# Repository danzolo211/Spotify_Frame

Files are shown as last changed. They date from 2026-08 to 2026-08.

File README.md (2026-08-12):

# GraceFrame ✝

An e-ink frame for the person you love. When she plays Spotify it shows her
music — album art, title, progress, and live synced lyrics where available.
When the music stops, it quietly turns into Scripture: **135 NIV verses** over **18 hand-drawn,
postcard-style scenes** (three crosses at dawn, a shepherd's field, a moonlit
starry night…), a new one every 20 minutes. Each verse is paired only with a
scene that has room for it, so the words are always complete and razor-sharp.

And it's hers to hold: a **phone app** (no App Store needed) shows a live
mirror of the screen, lets her browse and search every verse, save favorites
(they appear more often), pick scenes, and receive **notes** you send in
handwriting — from her Wi-Fi *or from anywhere* (see “Send her a note from
anywhere,” below).

Extra graces built in:
- **Quiet hours** — the frame holds one verse of peace all night, no flashing.
- **Special dates** — birthdays/anniversaries greet her by name in the morning.
- **Skip-proof e-ink** — rapid song-skipping never wears the panel (see below).

---

## 1. What's in this folder

```
Spotify_Frame/       <- the Arduino sketch (open Spotify_Frame.ino)
  data/              <- goes onto the ESP32's flash: verses, scenes, web app
  font_*.h           <- generated fonts (script, serif, sans)
  config.h           <- personalization: her name, dates, timezone, pins
  secrets.h          <- Wi-Fi + Spotify credentials (keep private!)
tools/               <- asset pipeline (already run — outputs are committed)
  make_backgrounds.py  fetch_verses.py  make_fonts.py
  spotify_auth.py      preview_app.py
WIRING.md            <- how to wire (do this first)
README.md            <- you are here
```

Everything in `Spotify_Frame/data` and the fonts are **already generated** —
you don't need to run any Python unless you want to tweak scenes or verses.

**Try the app right now** (before the hardware arrives):
`python tools/preview_app.py` → open http://localhost:8080 on this PC.

## 2. Wire it

Follow **WIRING.md** (5 minutes, 8 wires).

## 3. Arduino IDE setup (once)

1. Install **Arduino IDE 2.x**.
2. *File → Preferences → Additional boards manager URLs*, add:
   `https://espressif.github.io/arduino-esp32/package_esp32_index.json`
3. *Boards Manager* → install **esp32 by Espressif Systems**.
4. *Library Manager* → install:
   **GxEPD2** · **Adafruit GFX Library** · **ArduinoJson** · **TJpg_Decoder**
5. Optional if you use the IDE: install the LittleFS uploader (for step 6):
   download
   `arduino-littlefs-upload-*.vsix` from
   https://github.com/earlephilhower/arduino-littlefs-upload/releases
   and drop it into `C:\Users\<you>\.arduinoIDE\plugins\`
   (create the folder if needed), then restart the IDE.

## 4. Personalize

- `Spotify_Frame/config.h` — set `HER_NAME`, add `SPECIAL_DATES`
  (birthday, anniversary…), check `TIMEZONE`.
- `Spotify_Frame/secrets.h` — set **her home Wi-Fi** in `WIFI_SSID`/`WIFI_PASS`
  so she never has to configure anything, and confirm the Spotify values (see §9
  — the refresh token must belong to the account whose music you want shown).

## 5. Flash the firmware and data

Recommended from PowerShell on this PC:

```
cd C:\Users\Daniel Weber\OneDrive\Desktop
.\build_spotify_frame.ps1 -Upload -UploadData -Port COM6
```

That script pins a stable Arduino CLI, refuses to upload if compile fails, flashes
the firmware, then rebuilds and uploads the LittleFS data image with the scenes,
verses, and phone app.

If you use Arduino IDE instead, open `Spotify_Frame/Spotify_Frame.ino`. Select
**Tools →**
- Board: **ESP32S3 Dev Module**
- USB CDC On Boot: **Default / Disabled**
- PSRAM: **OPI PSRAM**
- Flash Size: **16MB**
- Partition Scheme: **16M Flash (3MB APP/9.9MB FATFS)**
- Port: your COM port

Click **Upload**. (If upload won't start: hold the BOOT button, tap RESET,
release BOOT, retry.)

## 6. Upload the data (verses, scenes, app)

The PowerShell command above already does this when you include `-UploadData`.

In Arduino IDE, with the sketch still open: press **Ctrl+Shift+P**, run
**“Upload LittleFS to Pico/ESP8266/ESP32”**. This copies `Spotify_Frame/data`
onto the board (~1 MB, takes a minute). Close the Serial Monitor first —
the uploader needs the port.

## 7. First light

- The frame connects to Wi-Fi and shows its first verse. Play Spotify
  anywhere on her account → the frame follows within ~5 seconds. If synced
  lyrics are available, one clean line appears under the album art.
- If Wi-Fi fails it opens its own network **GraceFrame-Setup** — join it
  with a phone and pick the home network. After credentials work, the panel
  confirms the SSID, IP address, and `graceframe.local`.

## 8. Put the app on her phone

1. On her phone (same Wi-Fi), open **http://graceframe.local**
   (if her phone balks at `.local`, use the frame's IP — it's printed in
   the Serial Monitor at boot).
2. Share → **Add to Home Screen**. Done — it opens full-screen like a real
   app, icon and all.

## 8½. Send her a note from anywhere

When you're **on her Wi-Fi**, the app's **Notes** tab sends straight to the
frame. When you're **not** — at your place, at work — use **`send-note.html`**:

1. Open `send-note.html` on **your** phone (email/AirDrop it to yourself, or
   host it anywhere — even a free GitHub Pages). Share → **Add to Home Screen**
   so it's one tap away.
2. Type a message, tap **Send to frame**. It appears on her frame within a few
   seconds, in handwriting — no matter whose network you're on.

How it works: the frame quietly checks a **private channel** on the free
[ntfy.sh](https://ntfy.sh) service; `send-note.html` posts to that same channel.
The channel name is a shared secret defined as `NOTES_TOPIC` in the ignored
`Spotify_Frame/secrets.h`. The QR generator reads it from there and puts it in
your private `send-note.html?token=...` link. To rotate it, set a new random
topic in `secrets.h`, rerun `python tools/make_qr.py`, and replace the private
QR/link. Notes pass through ntfy.sh's public relay, so keep them sweet, not
secret. Leave `NOTES_TOPIC` blank to turn the remote path off; the on-Wi-Fi
Notes tab still works.

Want to check the pipe is live? `python tools/test_remote_note.py` publishes a
test note and confirms it comes back.

## 9. Spotify

The refresh token in `secrets.h` already follows the account it was made
with. To follow **her** account instead, make sure her account (or your
family account) is the one that authorized it. To re-link:

```
python tools/spotify_auth.py --id CLIENT_ID --secret CLIENT_SECRET --device graceframe.local
```

(Client ID/secret from https://developer.spotify.com — the app needs
redirect URI `http://127.0.0.1:8888/callback`.)

---

## How the panel is protected (why skipping songs won't hurt it)

- A new song must **survive 2.5 s** before it's drawn — a skip-storm
  settles to a single refresh of the song she lands on.
- Full-screen refreshes are hard-limited to one per 3 s. Lyric/timer strip
  refreshes share a separate 900 ms gate so they can stay in sync without
  hammering the panel.
- Each **new song is a clean full refresh**, so the previous title/art is
  wiped instead of ghosting under the next one. Within the same song, lyric
  changes clean just the lyric strip. Timer ticks use one masked clean transaction
  over the bottom progress window: only the elapsed-time digits and the moving
  fill edge are cleaned through white, with the previous progress strip preserved
  during phase 1 so the fill cannot jump ahead during the clean pass. Small
  Spotify polling jitter is ignored; real seeks still snap.
- The elapsed time is **interpolated locally** between Spotify polls, so it
  stays accurate without extra network calls; the bar repaints every 10 s by
  default.
- Verse changes are calm full refreshes every 20 min (~70/day — panels are
  rated for 1,000,000+).
- During **quiet hours** the panel doesn't refresh at all; e-ink holds the
  image with zero power.

## Tweaks & tools

| I want to… | Do this |
|---|---|
| Change rotation timing, quiet hours, her name | In the app → Settings |
| Add/redraw scenes | edit `tools/make_backgrounds.py`, run it, re-do step 6 |
| Change verse list / translation | edit `tools/fetch_verses.py`, run it (`--translation KJV` etc.), re-do step 6 |
| Different fonts/sizes | edit `tools/make_fonts.py`, run it, re-flash (step 5) |
| Panel blank/scrambled | switch panel line in `config.h` (see WIRING.md #5) |

**Note on the text:** verses come from bolls.life's NIV text (the classic
1984 edition) for personal, non-commercial use — perfect for a gift, not
for resale.

Built with love (and a soldering-free ribbon cable). 🤍

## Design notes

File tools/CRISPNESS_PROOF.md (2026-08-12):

# Why the GraceFrame backgrounds cannot be blurry or grainy

A short proof that the art is crisp by construction — not by luck — at three
levels: the data, the transform that makes it, and the panel that shows it.
Any softness you ever see is your *screen viewer* rescaling hard pixels; it is
not in the bytes we ship, and it cannot appear on the e‑ink glass.

## 1. The data has exactly two states, so blur is unrepresentable
Each background is a packed 1‑bit bitmap: `BG_BYTES = 15000 = 400 × 300 / 8`
(`bgs.h`). Every pixel's value `L(x, y) ∈ {0, 1}` — black or white, nothing
between.

Blur *is*, by definition, a continuous luminance gradient across space: a ramp
that passes through **three or more** distinct levels within a small
neighborhood. A function whose codomain has cardinality 2 cannot take an
intermediate value, so it cannot form such a ramp. Between any two adjacent
pixels the transition is a single Heaviside step of width ≤ 1 pixel. **There is
no third level to interpolate ⇒ no blur can exist in the stored image.**

## 2. Generation is a threshold (a step function), never a filter
The generator (`make_backgrounds.py`) draws each scene at 4× (1600 × 1200) in
8‑bit grayscale, area‑resamples to 400 × 300, then maps every pixel with

```
T(L) = 1 if L < 128 else 0        # PIL convert("1", dither=NONE)
```

`T` is a pure step function, and `dither=NONE` means **no quantization error is
diffused into neighboring pixels** — the mechanism that would create scattered
mid‑tone dots ("grain") is simply never invoked. Composing any grayscale render
with `T` yields a codomain of `{0, 1}`. The 4× supersample‑then‑threshold also
pins the maximum edge‑transition width to exactly **one device pixel**
(Nyquist‑limited): edges are as sharp as the addressable grid allows — provably
the sharpest an image on this panel can be.

## 3. The panel is bistable, so blur is physically impossible on the glass
The Waveshare 4.2″ (SSD1683) drives each pixel to *full* black or *full* white;
it has **no grayscale addressing**. The display map `D : {0,1} → {black, white}`
is a 2‑level step, so the physical luminance is piecewise‑constant on the pixel
grid. A blur needs ≥ 3 luminance levels; with 2 it cannot form. (This is also
why the design forbids dithering: a dithered photo only *simulates* grey by
scattering black dots — the exact "grain" we refuse.)

## 4. Grain is driven to zero by construction — and measured, not assumed
Define a **speckle** as a foreground pixel whose 8 neighbours are all background
— an isolated floating dot, the visual signature of grain. The design language
(a) forbids dithering, and (b) enforces a minimum stroke width (≈1.4 px) and
minimum parallel‑line spacing (≈3 px). After threshold, no connected component
smaller than the feature size can survive, so free‑floating speckles → 0.

This is verified, not just argued: `audit_backgrounds.py` counts 8‑neighbour
speckles for every scene and **fails the build** if any scene's declared verse
zone contains a single foreground pixel. Current result: **0 zone violations**
across all 18 scenes (so words can never overlap art), and ≈0 floating speckles
on the day scenes — the handful that remain are *intentional* marks (sea spray
on the Great Wave; wheat awns; the ruled lines on the open book), not threshold
grain.

## Conclusion
Blur and grain aren't merely unlikely here — they are **excluded** by the
representation (2 states), the transform (threshold, zero error diffusion), and
the device (bistable). QED.

## Appendix: why live lyric and timer strips do not leave old pixels

The live lyric band and elapsed-time box use the same two-phase update:

```
1. set every pixel in rectangle R to white
2. refresh only R
3. draw the new content into R
4. refresh only R again
5. copy only R into the panel's previous-RAM baseline
```

Let `G_t(x,y)` be the visible glass state after update `t`, and `C_t(x,y)` be
the canvas state for the next content. For every pixel inside the strip
rectangle `R`, phase 1 forces `G_t(x,y)=white`. Phase 2 then drives the pixel
from white to exactly `C_t(x,y)`. Therefore the final state is
`G_t(x,y)=C_t(x,y)` for all `(x,y) in R`, independent of what was displayed at
`t-1`. Old glyphs cannot remain because the old state is not part of the second
transition.

For every pixel outside `R`, the clean helper writes neither current RAM nor
previous RAM, and the e-paper controller is asked to refresh only `R`. Therefore
`G_t(x,y)=G_{t-1}(x,y)` outside `R`. That is the key invariant:

```
previous_R_t == G_t on R
previous_outside_R_t == previous_outside_R_(t-1)
```

The lyric and progress rectangles are disjoint in the firmware constants:

```
Lyric band R_lyric: x = 0..399, y = 199..234
Transport icons:    y = 235..263
Progress bar box:   x = 16..383, y = 266..279
Elapsed time box:   x = 16..95,  y = 282..299
```

The full bottom strip contains the full timer/bar draw area:

```
Bar border: x = 18..381, y = 267..278
Bar fill:   x = 20..379, y = 269..276
Time text:  baseline y = 295; SansSmall digits occupy y = 286..294
```

`R_lyric` is disjoint from every progress rectangle, separated by the transport
icon rows. A lyric update uses `R = R_lyric`; it cannot blank, repaint, or
visibly flash the progress bar, timestamps, play/pause button, or skip arrows
because the clean helper writes only `R_lyric` into current RAM, previous RAM,
and the partial-refresh window.

Normal timer ticks also minimize flashing. The progress tick uses one masked
two-phase update over the bottom progress window. Its clean set is the small
elapsed-time box plus only the moving edge of the progress fill. Phase 1 copies
the previous displayed progress strip, not the future canvas, then whites only
the clean set. Phase 2 writes the final canvas. Therefore the fill cannot jump
ahead during the clean phase, and unchanged bar/frame pixels do not get a white
blink. If Spotify seeks backward and the bar must shrink, the firmware cleans
the fill interior so old black pixels are erased.

The coordinate invariant is explicit in `config.h`: lyrics are rows 199..234
and the progress/timestamp strip is rows 266..299. Because the lyric partial
push is confined to `LYRIC_BAND_*`, it cannot address the timestamp or progress
pixels at all. Progress ticks are also held away from lyric-line changes by
`PROGRESS_LYRIC_GUARD_MS`, so a legitimate timestamp clean pass is not scheduled
on top of the lyric transition and mistaken for lyric-induced erasing.

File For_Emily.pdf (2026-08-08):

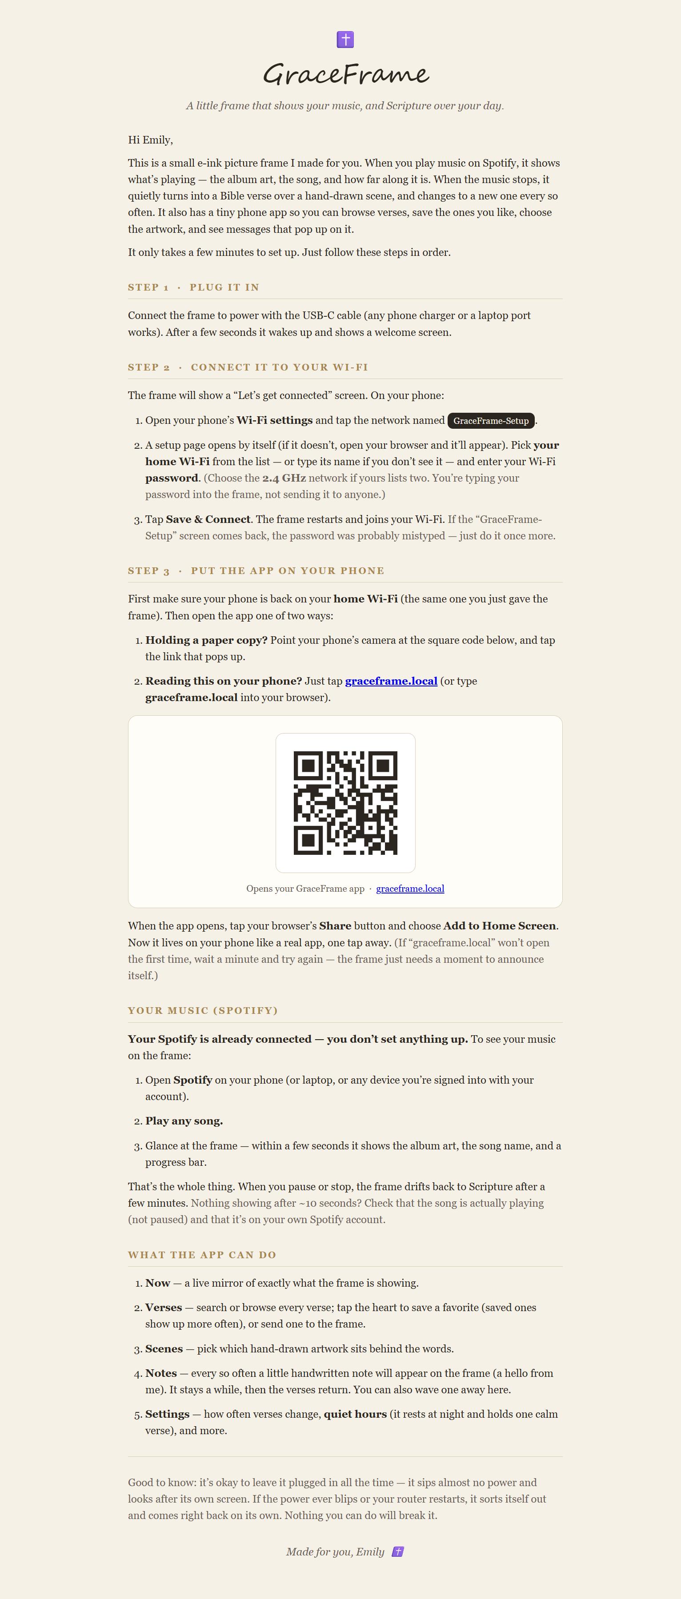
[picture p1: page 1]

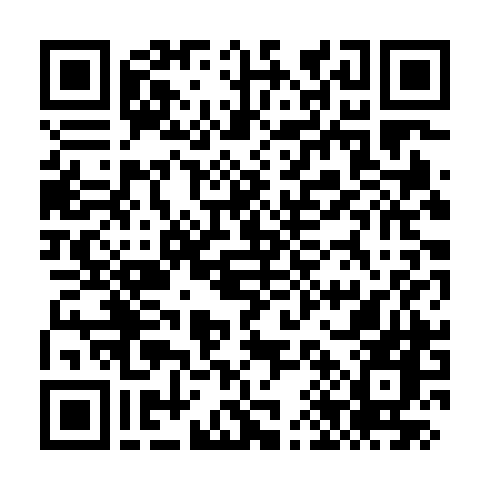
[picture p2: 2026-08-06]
graceframe_remote_qr.png

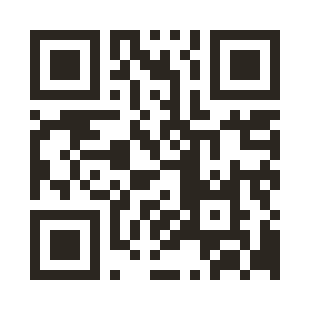
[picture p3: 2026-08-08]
graceframe_local_qr.png

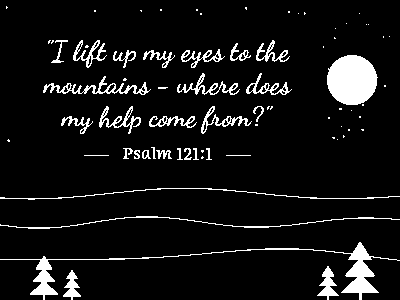
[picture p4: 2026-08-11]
tools/previews/review/13_moonlit-hills.png

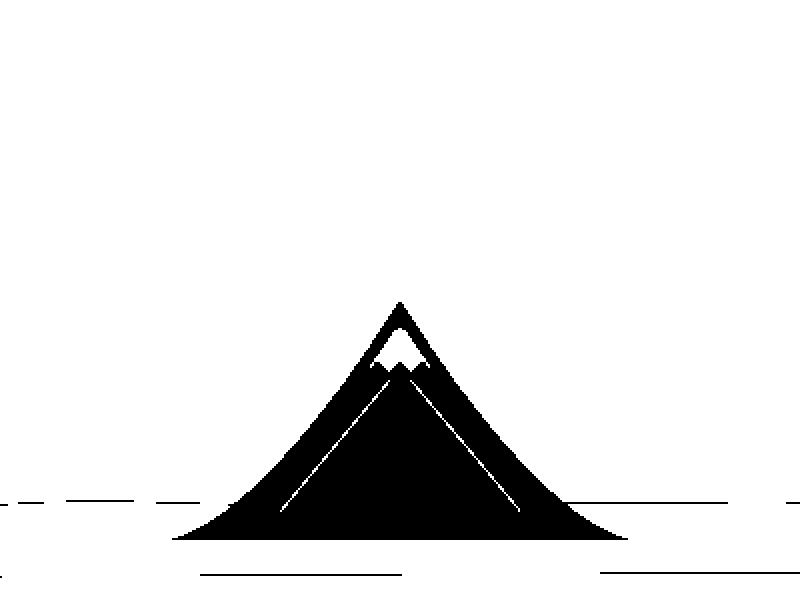
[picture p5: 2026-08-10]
tools/previews/015_fuji-serene.png

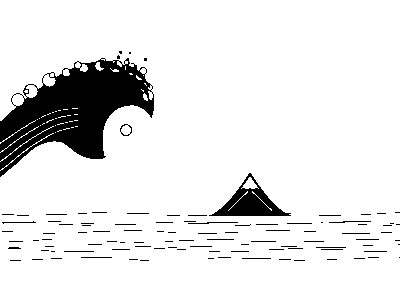
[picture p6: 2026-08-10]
tools/previews/review/15_great-wave_art.png

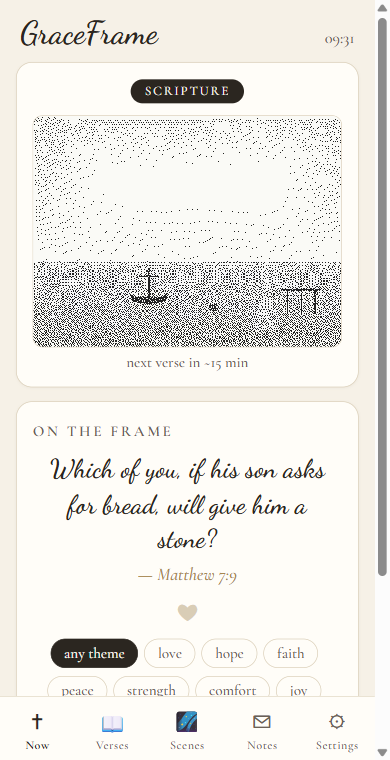
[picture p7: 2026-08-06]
tools/previews/app_now.png

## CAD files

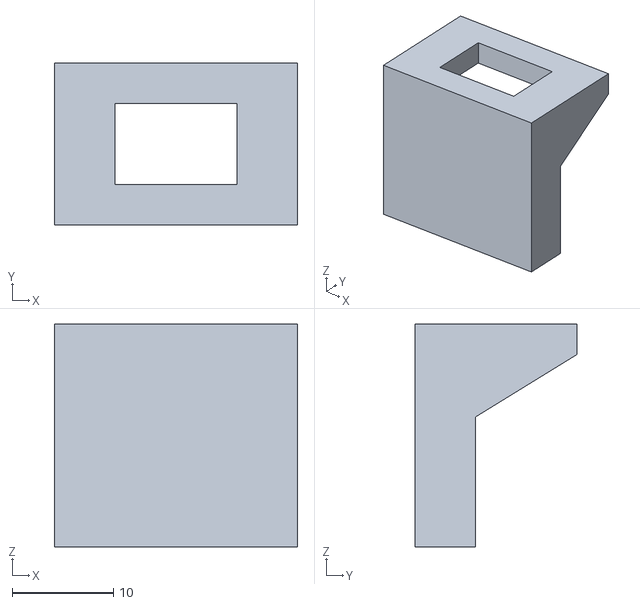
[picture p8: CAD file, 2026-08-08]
USBC_Base_Bracket.stl
24.0 x 16.0 x 22.0

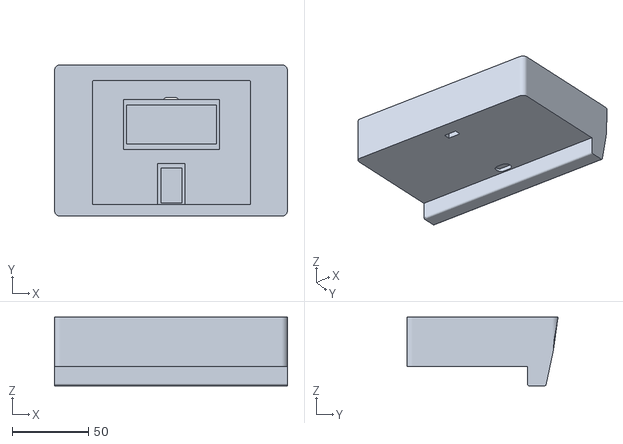
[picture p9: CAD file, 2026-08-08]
V_3_Daniel_Weber_Stand.stl
152.4 x 99.1 x 45.1

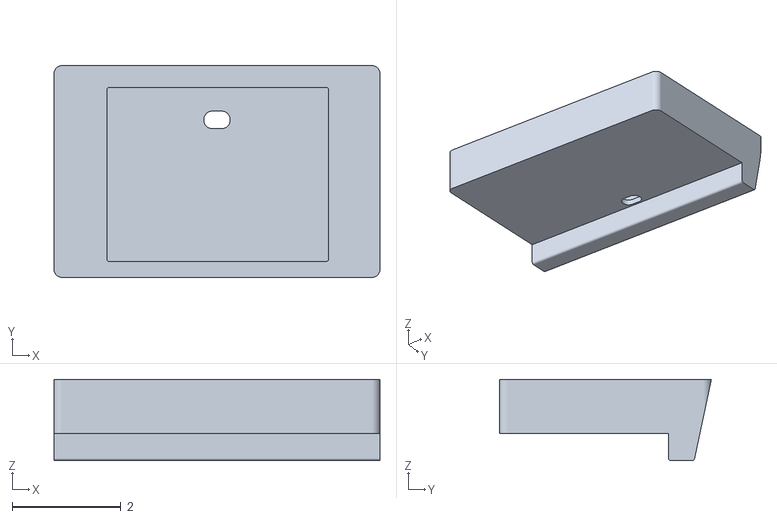
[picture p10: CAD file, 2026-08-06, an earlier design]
V_2_Daniel_Weber_Stand.stl
6.00 x 3.90 x 1.50

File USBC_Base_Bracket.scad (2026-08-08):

// USB-C base bracket for V_2_Daniel_Weber_Stand
// Holds a panel-mount USB-C female jack in the open bottom-center of the stand.
// Edit the numbers, then render (F6) and export STL.  Identical defaults to
// tools/make_base_bracket.py -- use whichever you prefer.
//
// Orientation when installed: +Z points to the REAR (the jack faces out the open
// back of the base); the FRONT face (Z=0) butts the solid front bezel so plugging
// a cable in can't push the bracket inward. Print with the FLOOR on the bed.

/* ---- tune to YOUR jack (mm) ---- */
pocket_depth = 22.0;  // front-to-back; keep == stand pocket depth so it wedges
width        = 24.0;
height       = 16.0;
floor_t      = 3.0;
panel_t      = 3.0;

aper_w   = 12.0;      // jack aperture width  (jack body + ~0.5 mm)
aper_h   = 8.0;       // jack aperture height
aper_yc  = 8.0;       // aperture center above the floor

screw_holes   = false; // set true if your jack mounts with 2 screws
screw_spacing = 16.0;  // center-to-center
screw_dia     = 2.2;   // M2 clearance

rail_t = 2.5; rail_h = 6.0;      // side rails
gusset_l = 8.0; gusset_h = 13.0; // panel-to-floor braces
$fn = 32;

module gusset(cx)
  // right-triangle brace on the panel front face, spanning rail width at x=cx
  translate([cx - rail_t/2, floor_t, pocket_depth - panel_t])
    rotate([0,90,0])
      linear_extrude(rail_t)
        polygon([[0,0],[0,-gusset_l],[gusset_h,0]]);

difference() {
  union() {
    // floor (rests on the stand's internal shelf)
    translate([-width/2, 0, 0]) cube([width, floor_t, pocket_depth]);
    // rear panel (solid; aperture cut below)
    translate([-width/2, 0, pocket_depth - panel_t]) cube([width, height, panel_t]);
    // side rails
    translate([-width/2, 0, 0]) cube([rail_t, rail_h, pocket_depth]);
    translate([ width/2 - rail_t, 0, 0]) cube([rail_t, rail_h, pocket_depth]);
    // gussets at the outer edges (clear of the central jack body)
    gusset(-width/2 + rail_t/2);
    gusset( width/2 - rail_t/2);
  }
  // jack aperture through the rear panel
  translate([-aper_w/2, aper_yc - aper_h/2, pocket_depth - panel_t - 0.5])
    cube([aper_w, aper_h, panel_t + 1.0]);
  // optional screw holes
  if (screw_holes)
    for (sx = [-screw_spacing/2, screw_spacing/2])
      translate([sx, aper_yc, pocket_depth - panel_t - 0.5])
        cylinder(d = screw_dia, h = panel_t + 1.0);
}

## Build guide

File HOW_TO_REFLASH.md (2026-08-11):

# How to re-flash GraceFrame

Follow this any time you update the frame. **Every final update should include
firmware and data**: code plus `Spotify_Frame/data` (verses, scenes, phone app).
It takes about 5 minutes.

> **This latest update needs BOTH A and B** (the code and the app both changed).

---

## Recommended PowerShell path

1. Plug the frame into this computer with the USB-C cable.
2. Close Serial Monitor or any terminal using the COM port.
3. Run:

```
cd C:\Users\Daniel Weber\OneDrive\Desktop
.\build_spotify_frame.ps1 -Upload -UploadData -Port COM6
```

The script refuses to upload stale firmware if compile fails. `-UploadData`
rebuilds and writes the LittleFS image at `0x610000`; Wi-Fi, Spotify credentials,
and settings in NVS are not touched.

## Arduino IDE fallback

Open **Arduino IDE** and open `Spotify_Frame/Spotify_Frame.ino`. In the **Tools**
menu, set these exactly:
   - **Board:** ESP32S3 Dev Module
   - **USB CDC On Boot:** Default / Disabled
   - **PSRAM:** OPI PSRAM
   - **Flash Size:** 16MB
   - **Partition Scheme:** 16M Flash (3MB APP/9.9MB FATFS)
   - **Port:** the COM port that appears when you plug the frame in (e.g. `COM5`).
     Not sure which? Unplug the frame, look at the list, plug it back in — the
     new one that appears is it.

---

## Part A — Flash the firmware (the code)

1. **Close the Serial Monitor** if it's open (it holds the port and blocks uploads).
2. Click the **Upload** button — the round **→** arrow at the top-left.
3. Wait until the bottom says **"Done uploading."** (about 1–2 minutes).

**If the upload won't start / errors out:** hold the **BOOT** button on the board,
tap **RESET** once, let go of **BOOT**, then click **Upload** again.

---

## Part B — Upload the data (verses, scenes, phone app)

1. Keep the same sketch open, **Serial Monitor still closed**.
2. Press **Ctrl + Shift + P** (opens the command palette).
3. Start typing and choose: **"Upload LittleFS to Pico/ESP8266/ESP32"**.
4. Wait about a minute for it to finish.

> Don't see that command? Install the uploader plugin once (README §3, step 5),
> restart Arduino IDE, and try again.

Uploading data replaces the LittleFS data partition, including generated
backgrounds/web app/verses and `favs.bin` if present. NVS values such as Wi-Fi
and Spotify credentials are separate and survive it.

---

## When you only changed one thing

| What changed | What to upload |
|---|---|
| Firmware / `.cpp` / `.h` / `.ino` / `config.h` | **A only** |
| Phone app (`data/www/…`), verses, or scenes (`data/…`) | **B only** |
| Not sure, or a big update like this one | **Do BOTH** |

---

## Done

Unplug it from the computer and plug it into any USB charger. It boots, joins
Wi-Fi, and shows a verse within a few seconds. Play Spotify and it appears.

**First time at her place:** it won't know her Wi-Fi yet, so it shows the
"Let's get connected" screen — that's expected. She sets it herself with the
letter in `For_Emily.html` (she never has to give you her password).

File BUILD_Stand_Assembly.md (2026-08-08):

# GraceFrame — Integrated Stand (V_3) Assembly

`V_3_Daniel_Weber_Stand.stl` is the original stand **edited** into an Aura-style,
self-contained frame: deepened 7 mm and given a built-in electronics bay.

Regenerate any time with `python tools/edit_stand.py` (all sizes are parameters at
the top). Preview: `tools/_v3_preview.png` (cutaway + back + side fit schematic).

> **`V_3` is in real millimeters** — import normally (no ×25.4 like the inch original).

## What changed vs V_2
- **+7 mm depth** → cavity ~24 mm (comfortable room for display + ESP + adapter).
- **USB-C port** cut through the back wall, bottom-center (cable exits behind = Aura).
- **Adapter cradle** (bottom-center): holds the GELRHONR right-angle USB-C→2-pin
  adapter, USB-C facing out the port, green terminal pointing up.
- **ESP tray** (mid): the 58×28 mm ESP32-S3 drops in, held against the back wall.
- **Right-side wire-relief channel**: the display is a 103 mm glove-fit in the
  103.6 mm pocket, so the 8 connector wires bend sideways into this channel instead
  of eating cavity depth.

## Parts
- Display: Waveshare 4.2" module (103.0 × 78.5 mm). ESP32-S3 dev board (58 × 28 mm).
- **GELRHONR USB-C-female → 2-pin screw terminal, 5V** (right-angle, solderless).
- 8× female–female jumper leads (display ↔ ESP). Any 5V USB-C charger.

## 1) Print `V_3`
- Orientation: **back face on the bed** (the flat back), so the cavity/trays print
  cleanly and the port needs no support.
- 0.2 mm layers, ≥3 perimeters, ≥25% infill.

## 2) Wire it (do this with power UNPLUGGED)
- e-paper ↔ ESP per `WIRING.md`: **VCC → 3.3V (never 5V)**, GND→GND, DIN→G21,
  CLK→G14, CS→G10, DC→G11, RST→G12, BUSY→G13.
- Adapter → ESP power:
  - Terminal **`+` → ESP `5V`/`VIN` pin**
  - Terminal **`−` → ESP `GND`**
  - ⚠️ **Polarity is on you** — reversed = dead board. Confirm the `+`/`−` printing.
  - ⚠️ 5 V goes to the ESP `5V` pin **only** — never to 3V3 or the panel's VCC.
- The ESP's regulator makes the 3.3 V the panel runs on. Flash via the ESP's own
  USB port before final assembly (the adapter powers it in daily use).

## 3) Assemble (electronics go in before the display)
1. Screw the two power wires into the adapter's terminal; **seat the adapter in the
   cradle**, USB-C nose aligned to the back port. (A dab of hot glue makes it captive.)
2. **Drop the ESP into its tray.**
3. Mount the display so its **connector/header is on the RIGHT edge**; tuck the 8
   jumper wires into the **right relief channel** so they bend back flat.
   - Set the firmware rotation so the image matches this orientation
     (`display.setRotation(...)` in `epaper.cpp`).
4. **Press the display into the front bezel** until flush; confirm nothing behind it
   is proud of the ~24 mm cavity.
5. Plug a USB-C charger into the back port → power on.

## Fit notes (measured, with margin)
Cavity ~24 mm. Adapter uses ~15 mm (≈9 mm to the display); ESP + pins/jumpers ~13 mm
(≈11 mm to the display). If your adapter is deeper than 15 mm or the module thicker
than ~4 mm, there's still headroom; if ever tight, **trim the ESP header pins**.

## Fallback (no reprint)
If you'd rather not reprint the stand, the earlier **`USBC_Base_Bracket.stl`** drops
into the existing base as a separate holder — same idea, no frame changes.

## Safety recap
- e-paper **VCC = 3.3 V only**; 5 V destroys the panel.
- Wire everything **unplugged**, then power.
- Adapter 5 V → ESP **5V/VIN** pin only; mind **polarity**.

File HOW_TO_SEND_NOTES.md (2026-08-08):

# How you send Emily notes

A note appears on her frame in handwriting, stays a while, then the verses
return. You can send one two ways.

## The easy way — from anywhere (recommended)

Works on any Wi-Fi or on cell data. You do **not** have to be at her place.

1. **One-time setup:** open **`graceframe_remote_qr.png`** (in this folder) on your
   computer screen and **scan it with your phone's camera**. Tap the link that pops
   up — it opens your private *"Send a note"* page.
2. On that page, tap your browser's **Share → Add to Home Screen** so it's one tap
   away from now on.
3. **To send a note:** open it, type your message, add your name, choose how long it
   should stay on the frame, and tap **Send to frame**. It shows up on her frame
   within a few seconds.

That link is your personal sender — keep it to yourself.

## The other way — when you're on her Wi-Fi

Open the app (**graceframe.local**) → **Notes** tab → type your message → **Send to
frame**. Same result, but this one only works while you're on her home Wi-Fi.

## Good to know

- Notes travel through a free public relay (ntfy.sh), so keep them sweet, not secret.
- If a note won't appear: make sure the frame is powered and on Wi-Fi, and that you
  used the **current** sender link (the one from `graceframe_remote_qr.png`).
- You can dismiss a note early from the app's **Notes** tab (**Dismiss current**).

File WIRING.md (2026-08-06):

# GraceFrame — Wiring

**Parts:** ESP32-S3 Dev Module · Waveshare 4.2" e-Paper Module (400×300, B/W)
· USB-C power adapter (5V) · the 8-wire cable that comes with the display.

## Connections

The Waveshare cable colors are standard, but double-check the labels printed
on the display's driver board — the label wins over the color.

| e-Paper pin | Wire color (typical) | ESP32-S3 pin | Purpose |
|---|---|---|---|
| **VCC** | gray / red | **3.3V** | power (NOT 5V!) |
| **GND** | brown / black | **GND** | ground |
| **DIN** | blue | **GPIO 21**  | SPI data (MOSI) |
| **CLK** | yellow | **GPIO 14**  | SPI clock |
| **CS** | orange | **GPIO 10**  | chip select |
| **DC** | green | **GPIO 11**  | data/command |
| **RST** | white | **GPIO 12**  | reset |
| **BUSY** | purple | **GPIO 13**  | busy signal |

If your board revision has a 9th **PWR** pin: connect it to **3.3V** as well.

```
        ESP32-S3 DevKit                     Waveshare 4.2" e-Paper
       ┌───────────────┐                   ┌──────────────────────┐
  USB-C│               │3V3 ─────────────── VCC   (+ PWR if present)
 power │               │GND ─────────────── GND
  in   │               │G21 ─────────────── DIN
       │               │G14 ─────────────── CLK
       │               │G10 ─────────────── CS
       │               │G11 ─────────────── DC
       │               │G12 ─────────────── RST
       │               │G13 ─────────────── BUSY
       └───────────────┘                   └──────────────────────┘
```

## Rules that save screens

1. **VCC to 3.3V, never 5V.** 5V will cook the panel.
2. Wire everything **with the power unplugged**, then plug in USB-C.
3. Seat the flat ribbon (FPC) between panel and driver board gently — flip
   the little black latch up, slide the ribbon in, press the latch down.
4. Keep the display flat; never press on the glass.
5. If the screen stays **blank or scrambled** after flashing: your panel is
   probably the older revision — open `GraceFrame/config.h` and switch
   `PANEL_GDEY042T81` → `PANEL_GDEW042T2` (two lines), re-upload.
6. If the image is **upside-down** for your frame build, change
   `display.setRotation(0)` to `2` in `epaper.cpp`.

Power draw is tiny (e-ink only sips power while refreshing), so any USB-C
phone charger works.

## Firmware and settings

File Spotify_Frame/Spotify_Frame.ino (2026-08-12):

/* =====================================================================
   GraceFrame — an e-ink frame that shows what she's listening to,
   and speaks Scripture over her day when the music stops.

   ESP32-S3 + Waveshare 4.2" e-paper (400x300)

   Modes
     SPOTIFY  music is playing: album art, title, artist, progress
     VERSE    rotating NIV verses over hand-drawn backgrounds
     NOTE     a note sent from the phone app
     SPECIAL  birthdays / anniversaries, shown in the morning

   The phone app lives at  http://graceframe.local
   Full setup guide in ../README.md — wiring in ../WIRING.md

   Libraries (Library Manager): GxEPD2, Adafruit GFX, ArduinoJson,
   TJpg_Decoder. Board: "ESP32S3 Dev Module", PSRAM: "OPI PSRAM",
   Flash Size: 16MB, Partition: "16M Flash (3MB APP/9.9MB FATFS)".
   ===================================================================== */

#include <Arduino.h>
#include <WiFi.h>
#include <LittleFS.h>
#include <time.h>
#include "esp_task_wdt.h"
#include "esp_heap_caps.h"

#include "config.h"
#include "state.h"
#include "util.h"
#include "epaper.h"
#include "render.h"
#include "verses.h"
#include "bgs.h"
#include "spotify.h"
#include "lyrics.h"
#include "netmgr.h"
#include "webapi.h"
#include "remote_notes.h"

// ------------------------------------------------------------ locals
static uint32_t nextPollAt = 0;
static String committedTrack = "";
static String pendingTrack = "";
static uint32_t pendingSince = 0;
static Track pendingInfo;
static uint32_t lastBarPush = 0;
static uint32_t lastCleanStripPush = 0;
static int shownBarFillW = -1;
static String shownElapsedText = "";
static uint8_t shownProgressStrip[(SCREEN_W / 8) * NP_BAR_STRIP_H];
static bool artValid = false;
static bool prevPlaying = false;
// Live-lyric display tracker. lyrShownIdx: -3 = band blank, -4 = instrumental note,
// >=-1 = the line index currently on the glass. (Kept at file scope so commitTrack
// can reset it in lock-step with lyricsOnNewTrack.)
static int lyrShownIdx = -3;
static int lyrShownState = LX_NONE;
static uint32_t lastLyricPush = 0;
static uint32_t specialShownAt = 0;
static uint32_t lastWifiCheck = 0;
static bool assetsOk = false;

// Local progress interpolation: Spotify is only polled every few seconds, but
// the elapsed time ticks smoothly. We remember the last reported position and
// advance it with the clock, so what's drawn matches the song without extra
// API calls. See liveProgressMs().
static long     progressAnchorMs = 0;
static uint32_t progressAnchorAt = 0;

// ------------------------------------------------------------ helpers
static bool timeSynced() { return time(nullptr) > 1600000000; }

static bool isNightNow() {
  if (!timeSynced()) return false;
  time_t now = time(nullptr);
  struct tm t;
  localtime_r(&now, &t);
  return t.tm_hour >= 20 || t.tm_hour < 6;
}

static bool inQuietHours() {
  if (!timeSynced()) return false;
  time_t now = time(nullptr);
  struct tm t;
  localtime_r(&now, &t);
  uint8_t h = t.tm_hour, s = settings.quietStart, e = settings.quietEnd;
  if (s == e) return false;
  return (s < e) ? (h >= s && h < e) : (h >= s || h < e);
}

// Pick a background that actually has room for this verse. Tries a handful of
// random (recent-avoiding) scenes; if none fit — a very long verse — it falls
// back to the roomiest one it saw, so the words are never chopped off.
static bool bgFitsVerse(const Verse& v, int bg) {
  if (bg < 0 || bg >= bgsCount()) return false;
  const BgInfo& b = bgsGet(bg);
  return renderVerseFits(v.text, v.ref, b.zw - 12, b.zh);
}

static int firstFittingBg(const Verse& v, bool night, const String& theme,
                          bool requireTheme) {
  int best = -1;
  long bestCap = -1;
  for (int i = 0; i < bgsCount(); i++) {
    const BgInfo& b = bgsGet(i);
    if (b.special) continue;
    if (b.night != night) continue;
    if (requireTheme && b.theme != theme) continue;
    if (!bgFitsVerse(v, i)) continue;
    long cap = (long)b.zw * b.zh;
    if (cap > bestCap) { bestCap = cap; best = i; }
  }
  return best;
}

static int pickBgFor(const Verse& v, bool night, const String& theme = "") {
  // a themed verse (e.g. "water") first tries a matching scene that fits, so the
  // wave verses land on the wave scenes; otherwise the normal rotation runs.
  if (theme.length()) {
    for (int tries = 0; tries < 10; tries++) {
      int bg = bgsPickThemed(theme.c_str(), night);
      if (bg < 0) break;
      if (bgFitsVerse(v, bg)) return bg;
    }
    int fit = firstFittingBg(v, night, theme, true);
    if (fit >= 0) return fit;
  }
  for (int tries = 0; tries < 24; tries++) {
    int bg = bgsPickRandom(night);
    if (bgFitsVerse(v, bg)) return bg;
  }
  int fit = firstFittingBg(v, night, "", false);
  if (fit >= 0) return fit;
  // Last-resort cross-polarity fallback: should never fire for the bundled data
  // because audit_backgrounds.py proves both day and night pools have a fit.
  for (int i = 0; i < bgsCount(); i++)
    if (!bgsGet(i).special && bgFitsVerse(v, i)) return i;
  return bgsPickRandom(night);
}

static void showRandomVerse(const String& cat = "", int forceBg = -1) {
  if (!assetsOk) return;
  int id = versesPickRandom(cat);
  if (id < 0) return;
  Verse v;
  if (!versesGet(id, v)) return;
  int bg = (forceBg >= 0 && bgFitsVerse(v, forceBg))
             ? forceBg : pickBgFor(v, isNightNow(), v.cat);
  renderVerse(v, bg);
  epdPush(PUSH_FULL);
  app.mode = MODE_VERSE;
  app.verseId = id;
  app.bgId = bg;
  app.verseShownAt = millis();
  versesHistoryAdd(id);
}

static void showVerseById(int id, int forceBg = -1) {
  Verse v;
  if (!versesGet(id, v)) return;
  int bg = (forceBg >= 0 && bgFitsVerse(v, forceBg))
             ? forceBg : pickBgFor(v, isNightNow(), v.cat);
  renderVerse(v, bg);
  epdPush(PUSH_FULL);
  app.mode = MODE_VERSE;
  app.verseId = id;
  app.bgId = bg;
  app.verseShownAt = millis();
  versesHistoryAdd(id);
}

static void showNoteScreen() {
  renderNote(app.note.text, app.note.from);
  epdPush(PUSH_FULL);
  app.mode = MODE_NOTE;
}

static void backToIdleScreen() {
  if (app.note.active) showNoteScreen();
  else showRandomVerse();
}

// ------------------------------------------------------------ spotify
// Where the song is right now, interpolated from the last poll so the elapsed
// time is honest between API calls (and never runs past the song's end).
static long liveProgressMs() {
  long p = progressAnchorMs;
  if (app.trackPlaying) p += (long)(millis() - progressAnchorAt);
  if (p < 0) p = 0;
  if (app.trackDuration > 0 && p > app.trackDuration) p = app.trackDuration;
  return p;
}

static void rememberProgressShown() {
  shownBarFillW = spotifyProgressFillWidth();
  shownElapsedText = spotifyElapsedTimeText();
  const uint8_t* buf = canvas.getBuffer();
  const int bytesPerRow = SCREEN_W / 8;
  for (int row = 0; row < NP_BAR_STRIP_H; row++) {
    memcpy(shownProgressStrip + row * bytesPerRow,
           buf + (NP_BAR_STRIP_Y + row) * bytesPerRow,
           bytesPerRow);
  }
}

// Draw the Now Playing screen with a fresh, interpolated position.
static void drawSpotify() {
  app.trackProgress = liveProgressMs();
  renderSpotify(spotifyArtBits(), artValid);
  rememberProgressShown();
}

static void pushSpotifyProgressTick() {
  app.trackProgress = liveProgressMs();
  int nextFillW = spotifyProgressFillWidth();
  String nextElapsed = spotifyElapsedTimeText();
  bool barChanged = (shownBarFillW < 0 || nextFillW != shownBarFillW);
  bool barShrank = (shownBarFillW >= 0 && nextFillW < shownBarFillW);
  bool elapsedChanged = (nextElapsed != shownElapsedText);
  EpdCleanRect cleanRects[3];
  int cleanCount = 0;

  if (barChanged) {
    renderSpotifyProgressBarOnly();
    if (barShrank || shownBarFillW < 0) {
      cleanRects[cleanCount++] = {NP_FILL_X, NP_FILL_Y, NP_FILL_MAX_W, NP_FILL_H};
    } else if (nextFillW > shownBarFillW) {
      int cleanStartW = shownBarFillW > NP_FILL_EDGE_OVERLAP
                          ? shownBarFillW - NP_FILL_EDGE_OVERLAP : 0;
      int cleanW = nextFillW - cleanStartW;
      if (cleanW > 0) {
        cleanRects[cleanCount++] = {
          NP_FILL_X + cleanStartW, NP_FILL_Y, cleanW, NP_FILL_H
        };
      }
    }
  }

  if (elapsedChanged) {
    renderSpotifyElapsedTimeOnly();
    cleanRects[cleanCount++] = {
      NP_TIME_LEFT_X, NP_TIME_LEFT_Y, NP_TIME_LEFT_W, NP_TIME_LEFT_H
    };
  }

  if (barChanged || elapsedChanged) {
    epdPushRegionMaskedClean(NP_BAR_STRIP_X, NP_BAR_STRIP_Y,
                             NP_BAR_STRIP_W, NP_BAR_STRIP_H,
                             cleanRects, cleanCount,
                             shownProgressStrip);
    rememberProgressShown();
    lastCleanStripPush = millis();
  }
  lastBarPush = millis();
}

static void pushSpotifyLyricStrip() {
  renderLyricBand();
  epdPushLyric(LYRIC_BAND_X, LYRIC_BAND_Y, LYRIC_BAND_W, LYRIC_BAND_H);
  uint32_t now = millis();
  lastCleanStripPush = lastLyricPush = now;
}

static bool lyricChangeWantedNow() {
  if (!settings.lyricsOn || app.mode != MODE_SPOTIFY) return false;

  int st = lyricsState();
  if (st != lyrShownState) {
    if (st == LX_READY) return app.trackPlaying;
    if (st == LX_INSTRUMENTAL) return true;
    return lyrShownIdx >= 0 || lyrShownState == LX_INSTRUMENTAL;
  }

  if (st != LX_READY || !app.trackPlaying) return false;

  long pos = liveProgressMs() + settings.lyricLeadMs;
  if (pos < 0) pos = 0;
  int idx = lyricsActiveIndex((uint32_t)pos);
  int want = (idx < 0) ? -3 : idx;
  return want != lyrShownIdx;
}

static bool lyricUpdatePendingNow() {
  if (lastCleanStripPush != 0 &&
      millis() - lastCleanStripPush < LYRIC_MIN_GAP_MS) return false;
  if (millis() - lastLyricPush < LYRIC_MIN_GAP_MS) return false;
  return lyricChangeWantedNow();
}

static bool lyricUpdateNearNow() {
  if (lastLyricPush != 0 &&
      millis() - lastLyricPush < PROGRESS_LYRIC_GUARD_MS) return true;
  if (lyricChangeWantedNow()) return true;
  if (!settings.lyricsOn || app.mode != MODE_SPOTIFY || !app.trackPlaying) return false;
  if (lyricsState() != LX_READY) return false;

  long pos = liveProgressMs() + settings.lyricLeadMs;
  if (pos < 0) pos = 0;
  int idx = lyricsActiveIndex((uint32_t)pos);
  int next = idx + 1;
  if (next < 0) next = 0;
  if (next >= lyricsCount()) return false;

  long until = (long)lyricsLineTimeMs(next) - pos;
  return until >= 0 && until <= PROGRESS_LYRIC_GUARD_MS;
}

static void commitTrack(const Track& t) {
  committedTrack = t.id;
  app.trackId = t.id;
  app.trackTitle = t.title;
  app.trackArtist = t.artist;
  app.trackAlbum = t.album;
  app.trackPlaying = t.playing;
  app.trackProgress = t.progress;
  app.trackDuration = t.duration;
  progressAnchorMs = t.progress;
  progressAnchorAt = millis();
  artValid = t.artUrl.length() ? spotifyFetchArt(t.artUrl) : false;
  renderSetLyric("", false);          // wipe the previous song's line before drawing
  drawSpotify();
  // A new song is a clean slate: always a full refresh so the previous title,
  // artist and art are wiped instead of ghosting under the new ones.
  epdPush(PUSH_FULL);
  app.mode = MODE_SPOTIFY;
  lastBarPush = millis();
  prevPlaying = t.playing;
  // Kick off the off-loop lyric fetch and align the on-screen tracker with the
  // just-set LOADING state (band is blank right now) so the first line renders
  // promptly and we never blink a blank-over-blank band.
  lyricsOnNewTrack(t.artist, t.title, t.album, t.duration, t.id);
  lyrShownState = LX_LOADING;
  lyrShownIdx = -3;
  lastLyricPush = millis();
  lastCleanStripPush = lastLyricPush;
}

static void spotifyTick() {
  if ((int32_t)(millis() - nextPollAt) < 0) return;

  Track t;
  int r = spotifyPoll(t);
  bool active = false;
  bool debouncingNew = false;   // waiting on the stability debounce to show a song

  if (r == SP_OK) {
    long predictedBeforePoll = liveProgressMs();
    bool sameKnownTrack = app.trackId.length() && t.id == app.trackId;
    app.trackDuration = t.duration;
    app.trackPlaying = t.playing;
    // keep app fields fresh for the phone even before anything is drawn
    app.trackId = t.id;
    app.trackTitle = t.title;
    app.trackArtist = t.artist;
    app.trackAlbum = t.album;

    if (t.playing && sameKnownTrack) {
      long delta = t.progress - predictedBeforePoll;
      progressAnchorMs = (delta > PROGRESS_JITTER_MS || delta < -PROGRESS_JITTER_MS)
                           ? t.progress : predictedBeforePoll;
    } else {
      progressAnchorMs = t.progress;
    }
    progressAnchorAt = millis();
    app.trackProgress = progressAnchorMs;

    if (t.playing) {
      app.lastMusicActive = millis();
      active = true;
    }

    bool showingThis = (app.mode == MODE_SPOTIFY && t.id == committedTrack);

    if (showingThis) {
      // Same song already on the panel. Every timer/icon update is a full
      // refresh for play/pause, while the timer/bar below use the same clean
      // white->content strip repaint as lyrics: crisp changed pixels without a
      // full-screen flash. The elapsed time is interpolated locally, so it stays
      // correct between Spotify polls.
      if (t.playing != prevPlaying) {                 // play <-> pause
        prevPlaying = t.playing;
        drawSpotify();
        epdPush(PUSH_FULL);
        lastCleanStripPush = lastBarPush = millis();
      } else if (t.playing && settings.progressS > 0) {
        uint16_t everyS = settings.progressS < MIN_PROGRESS_S
                            ? MIN_PROGRESS_S : settings.progressS;
        bool stripReady = (lastCleanStripPush == 0 ||
                           millis() - lastCleanStripPush >= LYRIC_MIN_GAP_MS);
        if (millis() - lastBarPush >= everyS * 1000UL &&
            stripReady && !lyricUpdateNearNow()) {
          pushSpotifyProgressTick();
        }
      }
    } else if (t.playing && !app.note.active) {
      // Music is playing but the panel is on a verse (or a different song).
      // Music has priority, so bring Now Playing (back) up. A note keeps
      // priority until it ends. The debounce lets a skip-storm settle to one
      // refresh of the song she lands on; debouncingNew re-polls the moment the
      // debounce clears so a newly-started song appears promptly.
      if (t.id != pendingTrack) {
        pendingTrack = t.id;
        pendingSince = millis();
        pendingInfo = t;
        debouncingNew = true;
      } else if (millis() - pendingSince >= TRACK_STABLE_MS) {
        commitTrack(t);
      } else {
        debouncingNew = true;
      }
    }
  } else if (r == SP_IDLE) {
    app.trackPlaying = false;
  }

  // music stopped long enough -> return to verses (a live note keeps the screen)
  if (app.mode == MODE_SPOTIFY && !app.trackPlaying &&
      millis() - app.lastMusicActive >= settings.idleMin * 60000UL) {
    committedTrack = "";
    pendingTrack = "";
    backToIdleScreen();
  }

  uint32_t interval =
      (active || millis() - app.lastMusicActive < 120000UL)
          ? POLL_ACTIVE_MS : POLL_IDLE_MS;
  if (r == SP_ERROR) interval = 15000;
  if (r == SP_COOLDOWN) interval = max(spotifyCooldownMs() + 500, (uint32_t)5000);
  // A newly-started song is one poll away from clearing the debounce; re-poll
  // right when it clears (not a full interval later) so it appears promptly.
  if (debouncingNew) {
    uint32_t elapsed = millis() - pendingSince;
    interval = elapsed < TRACK_STABLE_MS ? (TRACK_STABLE_MS - elapsed + 50) : 50;
  }
  nextPollAt = millis() + interval;
}

// ------------------------------------------------------------ lyrics
// Advances the on-screen lyric line in time with the song. First runs any due
// LrcLib fetch (off the commit's refresh path). Then, while a song with synced
// lyrics is on the panel, repaints the lyric band whenever the active line
// changes — a crisp white->content clean confined to that band, so there is no
// full-screen flash. The active line is recomputed from liveProgressMs() each
// tick, so pause freezes it, a seek jumps straight to the right line, and if
// clean-refreshes fall behind fast lines it always converges on the current one.
static void lyricsTick() {
  bool stripReady = (lastCleanStripPush == 0 ||
                     millis() - lastCleanStripPush >= LYRIC_MIN_GAP_MS);
  if (!settings.lyricsOn) {
    if (app.mode == MODE_SPOTIFY &&
        (lyrShownIdx >= 0 || lyrShownState == LX_INSTRUMENTAL) && stripReady) {
      renderSetLyric("", false);
      pushSpotifyLyricStrip();
      lyrShownIdx = -3;
      lyrShownState = LX_NONE;
    }
    return;
  }
  lyricsPoll();   // runs a due fetch once per song; bounded (stops on the first
                  // unreachable request) so it can't freeze the loop for long

  if (app.mode != MODE_SPOTIFY) { lyrShownState = LX_NONE; lyrShownIdx = -3; return; }

  int st = lyricsState();

  // Fetch result just changed -> settle the band once for the new state.
  if (st != lyrShownState) {
    int prev = lyrShownState;
    if (st == LX_INSTRUMENTAL) {
      if (!stripReady) return;
      lyrShownState = st;
      renderSetLyric("", true);
      pushSpotifyLyricStrip();
      lyrShownIdx = -4;                       // note shown
      return;
    }
    if (st != LX_READY) {                     // LOADING / UNAVAILABLE / NONE -> blank
      if (lyrShownIdx >= 0 || prev == LX_INSTRUMENTAL) {   // only if it wasn't already blank
        if (!stripReady) return;
        lyrShownState = st;
        renderSetLyric("", false);
        pushSpotifyLyricStrip();
      } else {
        lyrShownState = st;
      }
      lyrShownIdx = -3;
      return;
    }
    lyrShownState = st;
    lyrShownIdx = -3;                         // READY: force the current line to draw below
  }

  if (st != LX_READY || !app.trackPlaying) return;

  long pos = liveProgressMs() + settings.lyricLeadMs;
  if (pos < 0) pos = 0;
  int idx = lyricsActiveIndex((uint32_t)pos);
  int want = (idx < 0) ? -3 : idx;           // before the first line -> blank sentinel
  if (want != lyrShownIdx && stripReady &&
      (millis() - lastLyricPush) >= LYRIC_MIN_GAP_MS) {
    lyrShownIdx = want;
    renderSetLyric(idx >= 0 ? String(lyricsText(idx)) : String(""), false);
    pushSpotifyLyricStrip();
  }
}

// ------------------------------------------------------------ ticks
static void verseTick() {
  if (app.mode != MODE_VERSE || app.quiet || !assetsOk) return;
  if (millis() - app.verseShownAt >= settings.verseMin * 60000UL)
    showRandomVerse();
}

static void noteTick() {
  if (!app.note.active || app.note.until == 0) return;
  if ((int32_t)(millis() - app.note.until) >= 0) {
    app.note.active = false;
    if (app.mode == MODE_NOTE) {
      if (app.trackPlaying) {          // music is on: let Now Playing retake
        committedTrack = "";
        pendingTrack = "";
      } else {
        showRandomVerse();
      }
    }
  }
}

static void specialTick() {
  static uint32_t lastCheck = 0;
  static int lastDay = -1;
  if (millis() - lastCheck < 30000) return;
  lastCheck = millis();
  if (!timeSynced()) return;
  time_t now = time(nullptr);
  struct tm t;
  localtime_r(&now, &t);
  if (t.tm_mday != lastDay) {           // new day
    lastDay = t.tm_mday;
    app.specialShownToday = false;
  }
  if (app.specialShownToday || app.mode != MODE_VERSE || app.quiet) return;
  if (t.tm_hour < 7 || t.tm_hour >= 12) return;
  for (const SpecialDate& d : SPECIAL_DATES) {
    if (d.month == t.tm_mon + 1 && d.day == t.tm_mday) {
      renderSpecial(d.title, d.message, settings.herName);
      epdPush(PUSH_FULL);
      app.mode = MODE_SPECIAL;
      app.specialShownToday = true;
      specialShownAt = millis();
      return;
    }
  }
}

static void specialTimeout() {
  if (app.mode == MODE_SPECIAL && millis() - specialShownAt >= 90UL * 60000UL)
    showRandomVerse();
}

static void quietTick() {
  bool q = inQuietHours();
  if (q == app.quiet) return;
  app.quiet = q;
  if (app.mode != MODE_VERSE && app.mode != MODE_SPECIAL) return;
  if (q) {
    // goodnight: a verse of peace under a night sky, held all night
    if (!assetsOk) return;
    int id = versesPickRandom("peace");
    Verse v;
    if (id >= 0 && versesGet(id, v)) {
      int bg = pickBgFor(v, true);
      renderVerse(v, bg);
      epdPush(PUSH_FULL);
      app.mode = MODE_VERSE;
      app.verseId = id;
      app.bgId = bg;
      app.verseShownAt = millis();
      versesHistoryAdd(id);
    }
  } else {
    showRandomVerse("hope");   // new morning, new mercies
  }
}
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
void loop() {
  esp_task_wdt_reset();               // "still alive" — feed the watchdog
  webHandle();
  processPending();
  remoteNotesTick();
  spotifyTick();
  lyricsTick();
  verseTick();
  noteTick();
  specialTick();
  specialTimeout();
  quietTick();
  wifiTick();
  healthTick();
  delay(2);
}

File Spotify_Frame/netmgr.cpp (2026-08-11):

#include "netmgr.h"
#include "config.h"
#include "secrets.h"
#include "render.h"
#include "epaper.h"

#include <WiFi.h>
#include <WebServer.h>
#include <DNSServer.h>
#include <ESPmDNS.h>
#include <Preferences.h>

static bool tryJoin(const String& ssid, const String& pass, uint32_t ms) {
  if (!ssid.length()) return false;
  WiFi.mode(WIFI_STA);
  WiFi.setSleep(false);
  WiFi.setAutoReconnect(true);   // SDK also rejoins on its own after a drop
  WiFi.begin(ssid.c_str(), pass.c_str());
  Serial.printf("wifi: joining %s", ssid.c_str());
  uint32_t t0 = millis();
  while (WiFi.status() != WL_CONNECTED && millis() - t0 < ms) {
    delay(300);
    Serial.print(".");
  }
  Serial.println(WiFi.status() == WL_CONNECTED
                 ? " ok " + WiFi.localIP().toString() : " failed");
  return WiFi.status() == WL_CONNECTED;
}

bool netConnect() {
  Preferences p;
  p.begin("gf", false);                          // read-write: may set/clear flags
  bool force = p.getBool("force_setup", false);
  bool pending = p.getBool("wifi_pending", false);
  String ssid = p.getString("wifi_ssid", "");
  String pass = p.getString("wifi_pass", "");

  if (pending) {
    // Credentials she just entered in setup — test ONLY these. On success, lock
    // them in; on failure, reopen the portal with a clear message instead of
    // silently falling back to the built-in network (which would mask a wrong
    // password and leave the frame on the wrong Wi-Fi).
    p.putBool("wifi_pending", false);
    if (tryJoin(ssid, pass, 18000)) {
      p.putBool("wifi_failed", false);
      p.putBool("force_setup", false);
      p.end();
      return true;
    }
    p.putBool("wifi_failed", true);
    p.putBool("force_setup", true);              // arm the portal to reopen
    p.end();
    return false;
  }

  if (force) { p.end(); return false; }          // "re-run setup" was requested
  p.end();
  if (tryJoin(ssid, pass, 20000)) return true;
  return tryJoin(WIFI_SSID, WIFI_PASS, 20000);   // normal boot: fall back to built-in
}

// Clear the saved network and arm the setup portal for the next boot, so the
// frame comes up in first-time "choose your Wi-Fi" mode. Everything else in
// flash (Spotify link, verses, scenes, favorites, settings) is left untouched.
void netForgetWifi() {
  Preferences p;
  p.begin("gf", false);
  p.remove("wifi_ssid");
  p.remove("wifi_pass");
  p.putBool("force_setup", true);
  p.end();
}

// ------------------------------------------------------------- portal
static const char PORTAL_HTML[] PROGMEM = R"html(<!doctype html>
<html><head><meta charset=utf-8><meta name=viewport content="width=device-width,initial-scale=1">
<title>GraceFrame Setup</title><style>
*{box-sizing:border-box}body{font-family:-apple-system,BlinkMacSystemFont,"Segoe UI",sans-serif;
background:#f6f1e7;color:#2b2620;margin:0;display:flex;justify-content:center}
main{width:100%;max-width:430px;padding:28px 22px 36px}
.mark{font-family:Georgia,serif;font-size:34px;line-height:1;margin-bottom:12px}
h1{font-family:Georgia,serif;font-size:30px;margin:0 0 8px}
p{color:#645a4f;line-height:1.45;margin:0 0 14px}
.steps{background:#fffaf0;border:1px solid #d9cbb5;border-radius:14px;padding:14px 16px;margin:18px 0}
.steps b{color:#2b2620}ol{margin:8px 0 0 20px;padding:0;color:#4f463d;line-height:1.45}
label{display:block;margin:16px 0 6px;font-weight:700;color:#2b2620}
input{width:100%;padding:13px 12px;font-size:17px;border:1px solid #c9bda8;
border-radius:10px;background:#fffdf8}
button{margin-top:22px;width:100%;padding:15px;font-size:17px;font-weight:700;border:0;
border-radius:12px;background:#2b2620;color:#f6f1e7}
.hint{font-size:14px;color:#7c7063;margin-top:18px}
.show{font-weight:500;font-size:14px;color:#645a4f;margin-top:9px}
.show input{width:auto;margin-right:7px;vertical-align:middle}</style></head>
<body><main>
<div class=mark>+</div>
<h1>Connect GraceFrame</h1>
<p>Choose the home Wi-Fi network this frame should use.</p>
%BANNER%
<div class=steps><b>If your iPhone says this network has no Internet, tap
"Use Without Internet".</b><ol>
<li>Pick the home Wi-Fi below.</li>
<li>Enter the Wi-Fi password.</li>
<li>Tap Save &amp; Connect, then watch the frame.</li>
</ol></div>
<form method=POST action=/save onsubmit="return !!this.ssid.value.trim()">
<label>Home Wi-Fi</label>
<input name=ssid list=nets placeholder="Network name" autocomplete=off
 autocapitalize=off autocorrect=off spellcheck=false required>
<datalist id=nets>%OPTIONS%</datalist>
<label>Password</label>
<input id=pw name=pass type=password placeholder="Wi-Fi password"
 autocomplete=off autocapitalize=off autocorrect=off spellcheck=false>
<label class=show><input type=checkbox onchange="pw.type=this.checked?'text':'password'">Show password</label>
<button>Save &amp; Connect</button></form>
<p class=hint>GraceFrame uses 2.4 GHz Wi-Fi. If setup comes back with a red
message, the password probably needs a small fix.</p>
</main></body></html>)html";
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

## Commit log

2026-08-06 GraceFrame — e-ink Spotify + Scripture frame
    ESP32-S3 + Waveshare 4.2" e-paper (400x300). Shows now-playing (album art,
    title, live progress) while music plays; rotating NIV verses over hand-drawn
    scenes when it stops; notes sent from anywhere via an ntfy relay; and a phone
    web app served from the device.
    Sketch lives in Spotify_Frame/. secrets.h (Wi-Fi + Spotify + note token) is
    gitignored — copy it in locally; it is never committed.
    [V_2_Daniel_Weber_Stand.stl]
2026-08-07 Foolproof Now-Playing progress + robustness fixes
    Display: route changing glyphs through white so they can't ghost.
    - epdPushRegionClean(): blank a region to white, then paint it (both RAM
    banks reset to white first), back to back. Fixes the progress digits
    piling into an unreadable blob after many partial refreshes.
    - Progress bar (monotonic) uses a plain region refresh; elapsed digits and
    the play/pause icon use the clean path; total duration is static (drawn
    only on the song-change full refresh), so nothing accumulates.
    - In-song updates alternate bar/digits per tick (one refresh per interval).
    Robustness:
    - spotify.cpp downloadJpeg: free the buffer on a short/failed download
    (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
    [Spotify_Frame.ino, netmgr.cpp]
2026-08-07 Harden for gift day: self-healing, safe provisioning, honest Spotify link
    Reliability (permanent, unattended, must self-recover):
    - LittleFS: formatOnFail true->false (+retry). A transient mount fault
    (e.g. brownout mid-write) could otherwise REFORMAT the data partition
    and erase every verse/scene/favorite unrecoverably. Data now left intact.
    - Self-healing task watchdog (120s, panic-reboot): a wedged loop now
    auto-recovers instead of freezing. Can't false-trip (net calls cap ~8s).
    - Heap-floor safety reboot (healthTick): if the largest INTERNAL block
    drops critically low (2 reads/min, never mid-note), reboot to de-frag,
    guarding multi-day TLS-handshake fragmentation that would sil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
    [Spotify_Frame.ino, netmgr.cpp, spotify.h]
2026-08-08 Add Emily's setup letter + reflash guide; tidy special-date copy
    - For_Emily.html: self-contained, printable setup letter for Emily
    (Wi-Fi via the setup portal, "Spotify already connected — just play",
    scan-to-open QR embedded inline, plain-language how-to). Non-romantic.
    - HOW_TO_REFLASH.md: dummy-proof two-part flash guide (firmware + LittleFS).
    - graceframe_local_qr.png: regenerated crisp/print-friendly (graceframe.local).
    - config.h: fixed a grammar typo in the birthday message ("shown"->"shone");
    special dates otherwise unchanged (hearts + "The Day We Met" kept per Daniel).
    Firmware still compiles clean (39% flash / 23% RAM).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
2026-08-08 Emily letter: dummy-proof steps + Spotify usage + notes; add printable/textable copies
    - For_Emily.html: clearer step-by-step; app opens via QR (paper) OR a tappable
    graceframe.local link (phone); Spotify shown as simple numbered "play a song ->
    it appears" usage with a not-showing tip; notes section explains they arrive.
    - For_Emily.png / For_Emily.pdf: ready-to-text / ready-to-print copies of the letter.
    - HOW_TO_SEND_NOTES.md: dummy-proof guide for Daniel to send notes (remote sender
    via graceframe_remote_qr.png, or the app's Notes tab on her Wi-Fi).
2026-08-08 Fix Now-Playing timer ghosting: keep e-ink previous-RAM synced to the glass
    The bottom-strip partial refreshes wrote the whole canvas into the panel's
    "previous" RAM bank after physically refreshing only a sub-window. Because the
    progress bar and the elapsed digits repaint on alternating ticks, each tick
    poisoned the other region's baseline. The digit blank-to-white then cleared
    against digits the glass never actually showed, leaving ghost strokes of the
    old glyph -- the classic 8->3 residue that worsened as the song progressed.
    epdPush(PUSH_REGION) and epdPushRegionClean now sync only the window they
    physically refreshed via writeImagePartToPrevious, so previous-RAM always
    mirrors the glas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
2026-08-08 Add V3 stand + USB-C base bracket models, tooling, and assembly guide
    3D-printable stand (V_3_Daniel_Weber_Stand.stl) and USB-C base bracket
    (scad + stl), the Python tools that generate/edit them, preview renders,
    and the assembly instructions.
    [USBC_Base_Bracket.scad, USBC_Base_Bracket.stl, V_3_Daniel_Weber_Stand.stl]
2026-08-09 Now Playing: crisp full-refresh timer, faster pickup, music priority
    Fixes three field-tested issues on the frame:
    - Blurry timer: the elapsed digits went through e-ink partial refresh, whose
    fast waveform leaves text soft/greyish. Every timer and play/pause update is
    now a clean full refresh (razor-sharp, zero ghosting), floored to a 20s
    cadence so the brief flash stays gentle. Drops the split bar/digit partial
    path entirely.
    - Slow to show music: polled only every 15s when idle and needed a second poll
    ~5s later to clear the stability debounce, so Now Playing took ~20s to appear.
    Now polls every 5s when idle and re-polls the instant the 2.5s debounce
    clears, so a started so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
    [Spotify_Frame.ino]
2026-08-09 Add ukiyo-e wave scenes; audit + polish all backgrounds; water-verse affinity
    Art
    - New procedural 1-bit scenes (crisp threshold, no dither), tagged "water":
    great-wave (Hokusai homage), fuji-serene, crane-moon (night).
    - Upgraded shared helpers used across the set: sun_lined now reads as a warm
    sun instead of a spiky asterisk; sheep read as woolly sheep instead of dark
    lumps.
    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
2026-08-09 Spotify onboarding + on-demand Wi-Fi setup for handoff
    tools/spotify_auth.py
    - Add remote "--manual" sign-in: send her a link, she approves on her OWN phone
    and sends back the redirect address — her password never touches your machine.
    - Add "--push-token" to set an already-obtained refresh token by IP (no re-auth).
    - Stop auto-opening your signed-in browser (that silently linked your account);
    print the link so you open it in Incognito for her login.
    - A failed push to the frame is now non-fatal: it prints the token and exactly
    how to paste it into the app instead of dumping a traceback.
    Firmware: on-demand "Re-run Wi-Fi setup"
    - netForgetWifi() clears saved Wi-Fi and sets a force_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
    [netmgr.cpp]
2026-08-09 App: honest "Re-run Wi-Fi setup" feedback when firmware endpoint is missing
    If the /api/wifi/forget route isn't present (old firmware), the ESP32 SPA
    fallback serves index.html with 200, so the button used to falsely toast
    "Restarting…" while nothing happened. Now the handler checks the reply is JSON
    and, if not, tells you to flash the new firmware first. A dropped connection
    (the real reboot) is still treated as success.
2026-08-10 Add live synced lyrics (LrcLib) + safe Spotify test override
    - New lyrics.cpp/.h: fetch synced lyrics from lrclib.net (3s timeout,
    backoff + failure cache, PSRAM-buffered parse); advance a single centered
    line in time with the song via liveProgressMs().
    - Flashless per-line updates: a white->content clean of ONLY the lyric strip
    (epdPushLyric); the in-song timer moves off full-refresh too, so a song
    never triggers a full-screen flash. Now-Playing layout reflowed to fit the
    lyric band, proven disjoint from every other element.
    - /api/get drops album_name (it 404'd constantly on single/deluxe/remaster
    mismatches); /api/search fallback; live state in /api/status for debugging.
    - Lyr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
    [Spotify_Frame.ino]
2026-08-10 Refine backgrounds: rolled-stone tomb, clean Fuji, lighthouse beam, despeckle
    - empty-tomb: the rolled-away stone now reads as a pale, shaded boulder with
    a ground shadow instead of a black blob merging with the doorway.
    - fuji-serene: a clean iconic peak. Removed the cloud "layer-cake" slices and
    a stray summit hairline; snow is carved INSET so the black peak-tip and rim
    keep the pointed silhouette reading on the white sky. (great-wave's small
    Fuji inherits the crisp snow cap.)
    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
2026-08-10 Fix Wi-Fi setup portal reliability + test-before-save
    The setup AP ran in AP mode and re-scanned for networks on EVERY captive-portal
    probe; each scan briefly tears the SoftAP down, which is what made the phone
    "connect then nothing", hang on Save, and report "unable to join".
    - Run the AP in AP_STA and scan for networks ONCE at startup, then leave the
    radio alone so the AP stays rock-solid while she joins and types.
    - Open AP pinned to channel 1; captive-portal 302 redirect so the "Sign in to
    network" sheet pops reliably on iOS/Android.
    - Save now TESTS the credentials on the next boot: on success they're locked
    in; on failure the portal reopens with a clear red banner instead of
    s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
    [netmgr.cpp]
2026-08-10 Fix lyrics reliability + coverage (bulk read, multi-endpoint lookup)
    Two real bugs made most songs show no lyrics:
    1) Read: the parse streamed byte-by-byte off the TLS socket with a 3s cap,
    which is too slow for a ~10KB body -> the read timed out mid-parse and
    deserialize failed ("http 200 but 0 lines"). Now it bulk-reads the body
    with getString() and parses from memory, with the same 8s window the
    Spotify client already uses successfully.
    2) Coverage: only the exact /api/get (artist+track+duration) was tried, so
    any song whose Spotify length differs from LrcLib's by >2s, or any collab
    ("Drake, Future"), 404'd -- and the /api/search fallback returns hundreds
    of KB, too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
2026-08-10 Harden lyrics fetch: bound the request chain, refuse chunked search
    - Stop the lookup chain on the first NETWORK failure (unreachable/timeout)
    instead of burning ~8s each on up to 4 more doomed requests -> the loop can
    no longer freeze for tens of seconds when LrcLib is down. A clean 404 still
    falls through to the next endpoint, so song coverage is unchanged.
    - Refuse a /api/search reply with no Content-Length (chunked): it can't be
    size-bounded before reading, so getString() could have pulled hundreds of KB
    into RAM. Treated as "no lyrics" instead.
    [Spotify_Frame.ino]
2026-08-12 Stabilize progress strip refresh
    [Spotify_Frame.ino]
